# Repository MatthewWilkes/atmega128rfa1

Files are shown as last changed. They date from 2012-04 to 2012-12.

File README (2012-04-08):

This is open source hardware, licensed under the CERN open hardware licence.

This is a development board for the ATMega128rfa1 with optional USB interface.

It is intended to be a minimal viable board for low power applications, hence the low level of LEDs.  Programming of the chip can be done with minimal components installed (just the decoupling capacitor is required), but viable RF is expected to take a lot more.

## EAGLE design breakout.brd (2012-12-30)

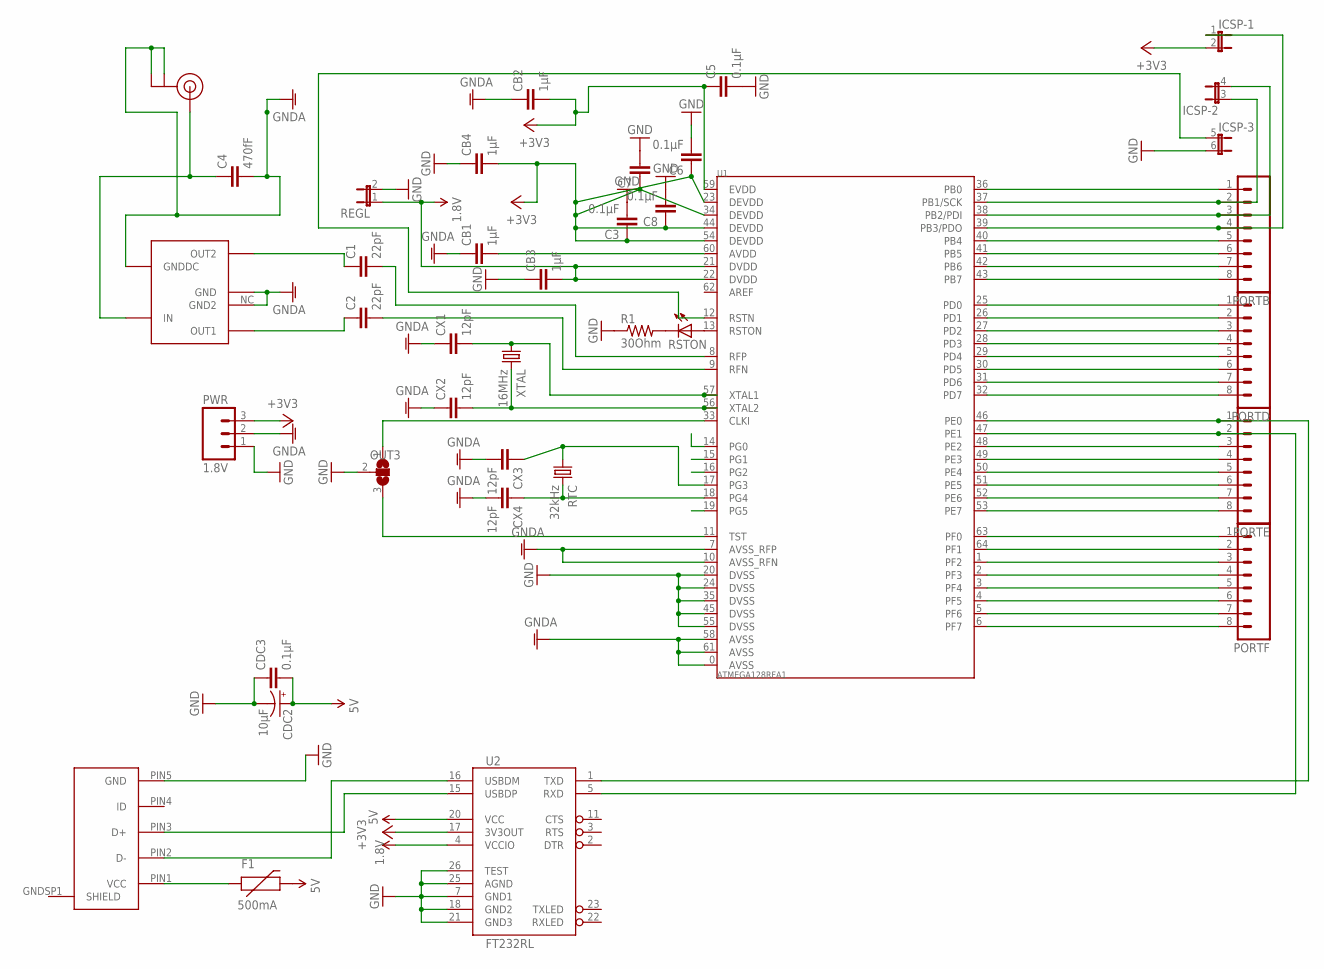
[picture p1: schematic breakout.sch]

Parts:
B1: 2.4GHz; WE-BAL
C1, C2: 22pF; C0603
C3, C5, C6, C8: 0.1µF; C0201
C4: 470fF; C0402
C7: C-EUC0201; C0201
CB1, CB2, CB3, CB4: 1µF; C0603
CDC2: 10µF; EIA3216
CDC3: 0.1µF; C0201
CX1, CX2, CX3, CX4: 12pF; C0603
F1: 500mA; 0603
ICSP: JP3QE; JP3Q
JP1: USBMICROB; MICROB
OUT3: SOLDERJUMPERNO; SJ_2
PORTB: M081X08; 1X08
PORTD: M081X08; 1X08
PORTE: M081X08; 1X08
PORTF: M081X08; 1X08
PWR: 1.8V; 1X03
R1: 30Ohm; R0603
REGL: JP1E; JP1
RSTON: LEDCHIPLED_0603; CHIPLED_0603
RTC: 32kHz; TC26H
U1: ATMEGA128RFA1; QFN-64
U2: FT232RL; SSOP28DB
U$6: U.FL
XTAL: 16MHz; HC49UP

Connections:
1.8V: CB3.2, REGL.1, U1.21 (DVDD), U1.22 (DVDD), U2.4 (VCCIO)
5V: CDC2.A (+), CDC3.2, F1.2, U2.20 (VCC)
+3V3: C3.1, C5.1, C6.1, C7.1, C8.1, CB2.2, CB4.2, ICSP.2, PWR.3, U1.23 (DEVDD), U1.34 (DEVDD), U1.44 (DEVDD), U1.54 (DEVDD), U1.59 (EVDD), U2.17 (3V3OUT)
GND: C3.2, C5.2, C6.2, C7.2, C8.2, CB3.1, CB4.1, CDC2.C (-), CDC3.1, ICSP.6 (2), JP1.PIN5 (GND), OUT3.2, PWR.1, R1.1, REGL.2, U1.20 (DVSS), U1.24 (DVSS), U1.35 (DVSS), U1.45 (DVSS), U1.55 (DVSS), U2.7 (GND1), U2.18 (GND2), U2.21 (GND3), U2.25 (AGND), U2.26 (TEST)
GNDA: B1.GND, B1.GNDDC, B1.NC (GND2), C4.2, CB1.1, CB2.1, CX1.1, CX2.1, CX3.2, CX4.2, PWR.2, U1.0 (AVSS), U1.7 (AVSS_RFP), U1.10 (AVSS_RFN), U1.58 (AVSS), U1.61 (AVSS), U$6.P$1 (GND), U$6.P$2 (GND)
unnamed: CX3.1, RTC.1, U1.17 (PG3)
unnamed: CX4.1, RTC.2, U1.18 (PG4)
unnamed: ICSP.1, PORTB.4, U1.39 (PB3/PDO)
unnamed: CB1.2, U1.60 (AVDD)
unnamed: B1.OUT1, C2.1
unnamed: ICSP.3 (1), PORTB.2, U1.37 (PB1/SCK)
unnamed: OUT3.1, U1.33 (CLKI)
unnamed: PORTD.1, U1.25 (PD0)
unnamed: C2.2, U1.9 (RFN)
unnamed: CX2.2, U1.56 (XTAL2), XTAL.2
unnamed: PORTD.2, U1.26 (PD1)
unnamed: ICSP.5 (1), U1.12 (RSTN)
unnamed: CX1.2, U1.57 (XTAL1), XTAL.1
unnamed: C1.2, U1.8 (RFP)
unnamed: B1.OUT2, C1.1
unnamed: PORTD.3, U1.27 (PD2)
unnamed: PORTD.4, U1.28 (PD3)
unnamed: JP1.PIN3 (D+), U2.15 (USBDP)
unnamed: PORTD.5, U1.29 (PD4)
unnamed: PORTD.6, U1.30 (PD5)
unnamed: PORTD.7, U1.31 (PD6)
unnamed: PORTD.8, U1.32 (PD7)
unnamed: PORTE.1, U1.46 (PE0), U2.1 (TXD)
unnamed: PORTE.2, U1.47 (PE1), U2.5 (RXD)
unnamed: PORTE.3, U1.48 (PE2)
unnamed: PORTE.4, U1.49 (PE3)
unnamed: PORTE.5, U1.50 (PE4)
unnamed: PORTE.6, U1.51 (PE5)
unnamed: PORTE.7, U1.52 (PE6)
unnamed: PORTE.8, U1.53 (PE7)
unnamed: PORTF.1, U1.63 (PF0)
unnamed: PORTF.2, U1.64 (PF1)
unnamed: PORTF.3, U1.1 (PF2)
unnamed: PORTF.4, U1.2 (PF3)
unnamed: PORTB.1, U1.36 (PB0)
unnamed: PORTB.5, U1.40 (PB4)
unnamed: PORTB.6, U1.41 (PB5)
unnamed: PORTB.7, U1.42 (PB6)
unnamed: PORTB.8, U1.43 (PB7)
unnamed: OUT3.3, U1.11 (TST)
unnamed: JP1.PIN2 (D-), U2.16 (USBDM)
unnamed: F1.1, JP1.PIN1 (VCC)
unnamed: RSTON.A, U1.13 (RSTON)
unnamed: R1.2, RSTON.C
unnamed: ICSP.4 (2), PORTB.3, U1.38 (PB2/PDI)
SMA: B1.IN, C4.1, U$6.P$3 (SIGNAL)
TCK: PORTF.5, U1.3 (PF4)
TDI: PORTF.8, U1.6 (PF7)
TDO: PORTF.7, U1.5 (PF6)
TMS: PORTF.6, U1.4 (PF5)

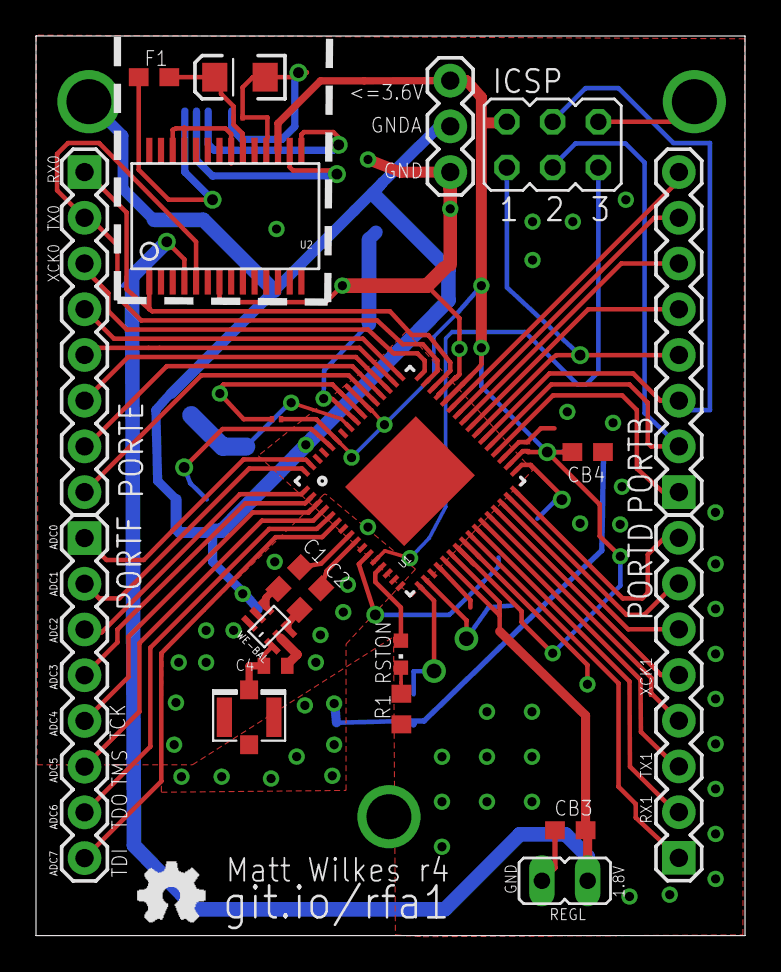
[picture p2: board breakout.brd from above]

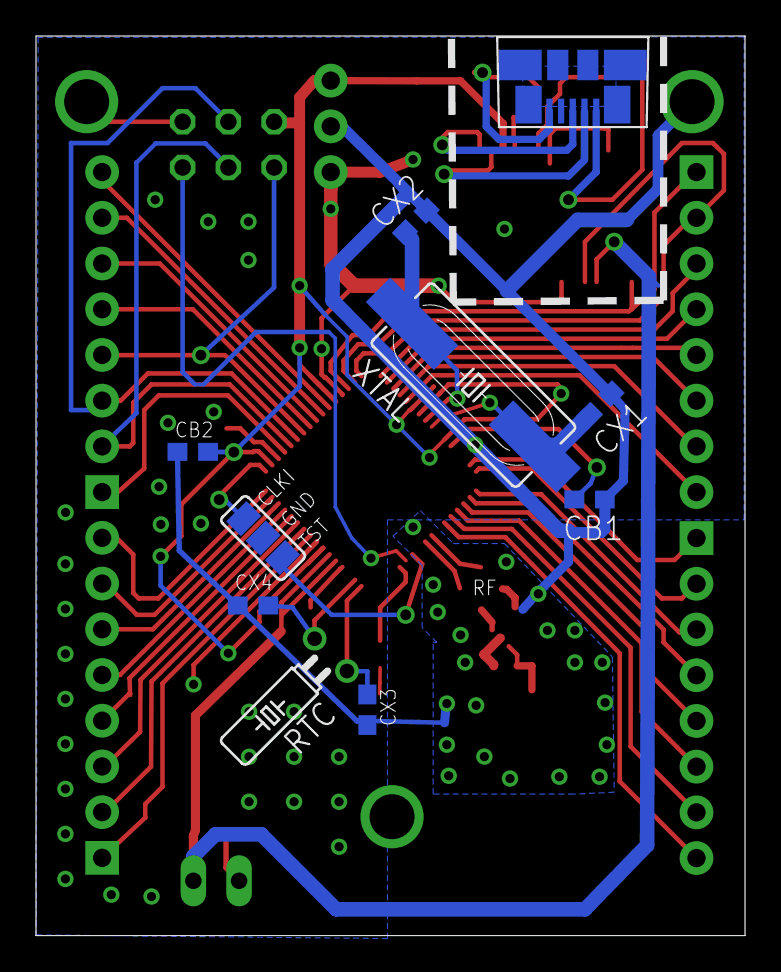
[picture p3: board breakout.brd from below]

Board: 2 copper layers, 39.4 x 50.0 mm, 36 parts (10 on the bottom side), 55 nets.

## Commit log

2012-03-30 Current status
    [breakout.brd, breakout.sch]
2012-04-01 Better routing of source voltages.
    [breakout.brd, breakout.sch]
2012-04-01 DRC fixes
    [breakout.brd]
2012-04-01 Fix airwires, albeit with suboptimal RF and analog ground connection. Maybe we need some chokes.
    [breakout.brd]
2012-04-01 Add +1V8 copper fill
    [breakout.brd]
2012-04-01 Use GNDDC from the balun for the SMA antenna ground
    [breakout.brd, breakout.sch]
2012-04-01 DRC fix
    [breakout.brd]
2012-04-01 More attempts at an RF plane
    [breakout.brd]
2012-04-08 misc uncommitted updates
    [breakout.brd, breakout.sch]
2012-04-08 Schematic USB support
    [breakout.brd, breakout.sch]
2012-04-08 Normalise some packages, the caps we have are 0603 not 0504, whatever that is.
    [breakout.brd, breakout.sch]
2012-04-08 Remove 3.3V rail between USB and regulator, it can only source 50mA. DRC fixes. Make bottom copper fill 1.8V regl output.
    [breakout.brd]
2012-04-08 Add second copper pour to bottom layer to isolate RF circuitry
    [breakout.brd]
2012-04-08 Move usb closer to the new edge
    [breakout.brd]
2012-04-08 USB silkscreen
    [breakout.brd]
2012-04-09 Tie test low
    [breakout.brd, breakout.sch]
2012-04-09 Remove un-needed 1.8V wire as the bottom plane handles it now
    [breakout.brd]
2012-04-09 Silkscreening for JTAG
    [breakout.brd, breakout.sch]
2012-04-09 Reattach 3.3V, it can source 50mA and the 128rfa1 at full power TX only needs 20ish.
    [breakout.brd]
2012-04-09 Routing perfectionism
    [breakout.brd]
2012-04-27 Bind grounds with tented vias, some rerouting
    [breakout.brd, breakout.sch]
2012-04-27 Impedence matching
    [breakout.brd, breakout.sch]
2012-04-27 Silkscreens and fiddling
    [breakout.brd, breakout.sch]
2012-04-27 Move GNDA bottom plane to avoid a top layer digital line
    [breakout.brd, breakout.sch]
2012-04-27 Ground coupling tented via underneath the atmega
    [breakout.brd]
2012-04-27 Switch CLKI/TST jumper with a 3way including a central GND
    [breakout.brd, breakout.sch]
2012-04-27 Widen some ground traces
    [breakout.brd]
2012-04-27 Ensure GPIO is on a .1" grid vertically
    [breakout.brd]
2012-04-27 Ensure GPIO is on a .1" grid horizontally
    [breakout.brd]
2012-04-27 Remove some ugly vias
    [breakout.brd]
2012-04-27 Move a via into the GND layer
    [breakout.brd]
2012-04-27 Dodge power out of the way of a silkscreen line
    [breakout.brd]
2012-04-27 Move PORTE silkscreen to be clearer
    [breakout.brd]
2012-05-09 Multiple fixes to decoupling, board layouts, this is okay
    [breakout.brd, breakout.sch]
2012-05-09 Thicken up +3V3 rail
    [breakout.brd]
2012-05-09 Erc errors
    [breakout.brd, breakout.sch]
2012-05-09 Realign power and improve overall silking. Switched to Vector font
    [breakout.brd]
2012-05-09 Persist font vectoring
    [breakout.brd]
2012-05-09 Layout tweaks
    [breakout.brd, breakout.sch]
2012-05-09 Dewonky some of PORTE
    [breakout.brd]
2012-05-09 Route nicifying
    [breakout.brd]
2012-05-09 Line straightening
    [breakout.brd]
2012-05-09 Route prettifying
    [breakout.brd]
2012-05-09 Cleanup ground pours to give some more room around the RF ground, fix airwires
    [breakout.brd]
2012-05-09 Additional GND bridging via
    [breakout.brd]
2012-05-10 Remove silking for 0.1µF cap
    [breakout.brd]
2012-05-10 Layout tidying
    [breakout.brd, breakout.sch]
2012-05-10 Align power to 0.1 inch horiz
    [breakout.brd]
2012-05-21 Various fixes, r3 ordered
    [breakout.brd, breakout.sch]
2012-06-08 Various r4 changes
    [breakout.brd]
2012-09-12 Switch to XML based representation
    [breakout.brd, breakout.sch]
2012-12-30 Switch to using a u.fl connector from SMA
    [breakout.brd, breakout.sch]
2012-12-30 Reduce the size of the radio copper pour to fit u.fl
    [breakout.brd]
2012-12-30 Bump revision number
    [breakout.brd]

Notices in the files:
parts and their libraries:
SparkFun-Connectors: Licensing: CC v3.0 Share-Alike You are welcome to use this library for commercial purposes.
